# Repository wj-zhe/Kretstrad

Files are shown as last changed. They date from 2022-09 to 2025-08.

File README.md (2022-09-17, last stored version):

# Kretsträd - a Seeeduino Xiao BLE based 34 keys split keyboard running on ZMK firmware

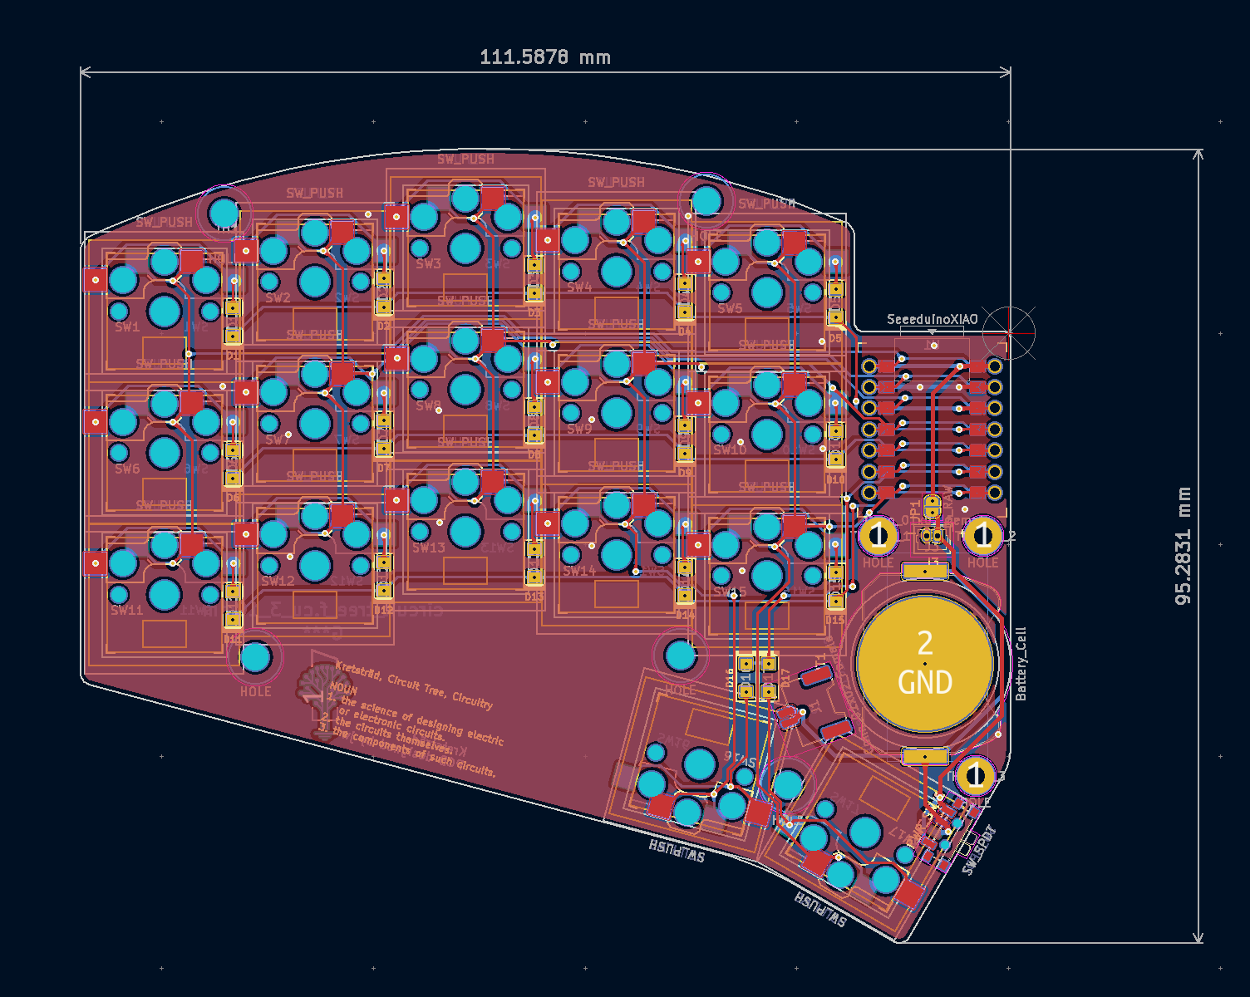
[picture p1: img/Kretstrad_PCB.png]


## Build instruction

This keyboard is able to accommodate two types of batteries. My own prototypes used two LIR2032
rechargeable cell batteries, simply because they seem to be more geeky to my eyes. In such case, all
you have to buy is No.1-10 on BOM list. However, the small 40 mAh capacity requires a charge every
5-7 days on master side and roughly 14 days on peripheral side.

So, if you prefer longivity and less frequent charge, use 501220 lithium ion battery pack rated at
100 mAh. In this case, you should buy everything on BOM except No.9-10. Also, remember to close JP1
jumper on the back side.

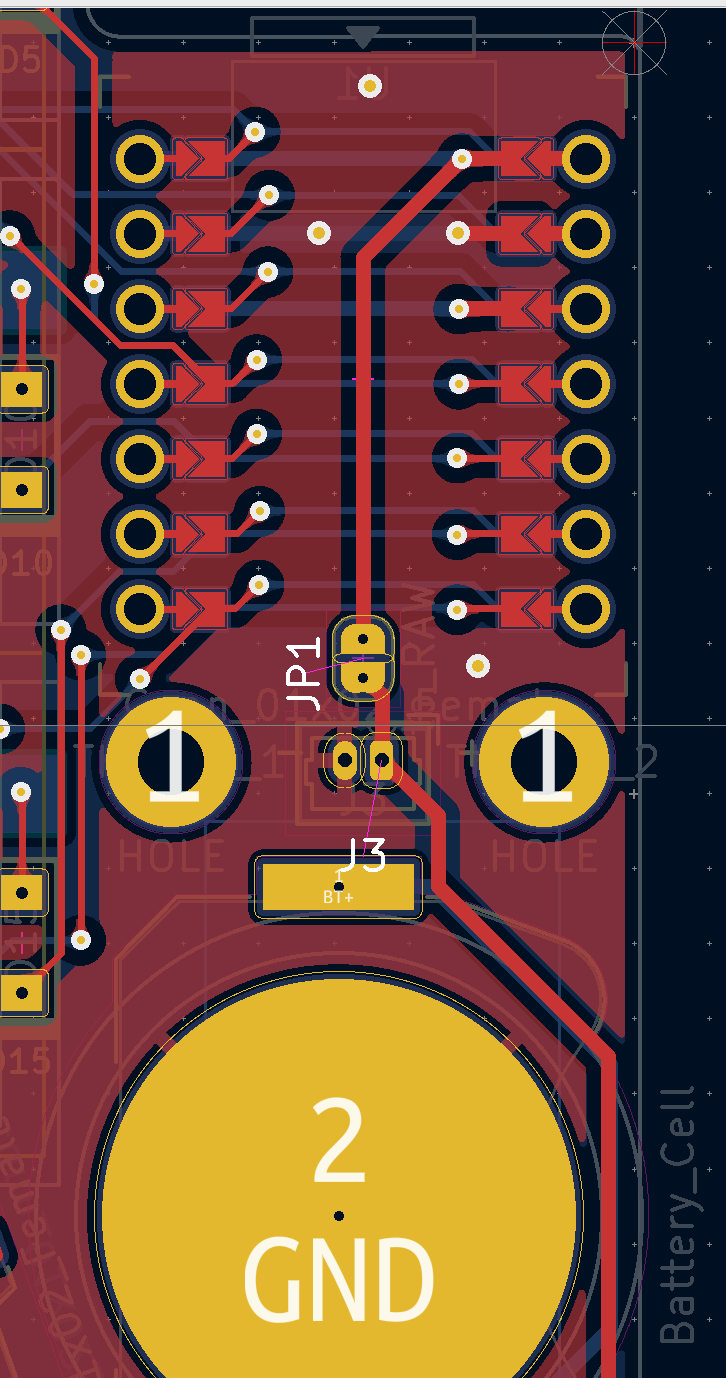
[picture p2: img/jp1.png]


Other than that, the build process is quite straight forward:
  - order PCB with readily printable [gerber files](/pcb/gerber). [KiCad files](/pcb) are also in
    place, incase you want to make change;
  - buy components depending on battery type;
  - solder everything into place
  - put in Kailh Choc V1 switches. Yes, this keyboard supports only V1 Choc as for now;
  - Done!

Files for acrylic stacked case are located in [/case](/case) directory. But only cell battery
version is provided. If you chose 501220 battery pack, please remember to make correspondent
modifications.

In case MCU/battery covers are needed, you can draw yourself based on case files and install them
with additional M2x9+3 brass insert spacers placed at TH_PCB_1 ~ TH_PCB_3.

## BOM

| No. | Designator | Package | Quantity |
| :--- | :--- | :--- | :--- |
| 1  | U1 | Seeeduino Xiao BLE (nRF52840) | 2 |
| 2  | D1 ~ D17 | Diode SOD123 THT 1N4148WS 1206 | 34 |
| 3  | SW1 ~ SW17 | Kailh CHOC switch socket PG1350 | 34 |
| 4  | TH1 ~ TH5 | Brass insert M2x5 | 10 |
| 5  | TH1 ~ TH5 | M2x3 flat head screws | 20 |
| 6  | TH_PCB_1 ~ TH_PCB_3 | Plated self-clinching standoff, M2x3 | 6 |
| 7  | TH_PCB_1 ~ TH_PCB_3 | M2x5 flat head screws | 6 |
| 8  | PWR_SW_1,PWR_SW_2 | PCM12SMTR | 2 |
| 9  | J3 | Molex_PicoBlade_53047-0210_1x02_P1.25mm_Vertical,1 | 2 |
| 10 | BT1,BT2 | Battery Holder BK-912 | 2 |
| 11 | J1,J2 | Molex_Panelmate_53780-0270_1x02-1MP_P1.25mm_Horizontal,2 | 2 |

## Firmware

https://github.com/wj-zhe/zmk-config/tree/master/config/boards/shields/kretstrad

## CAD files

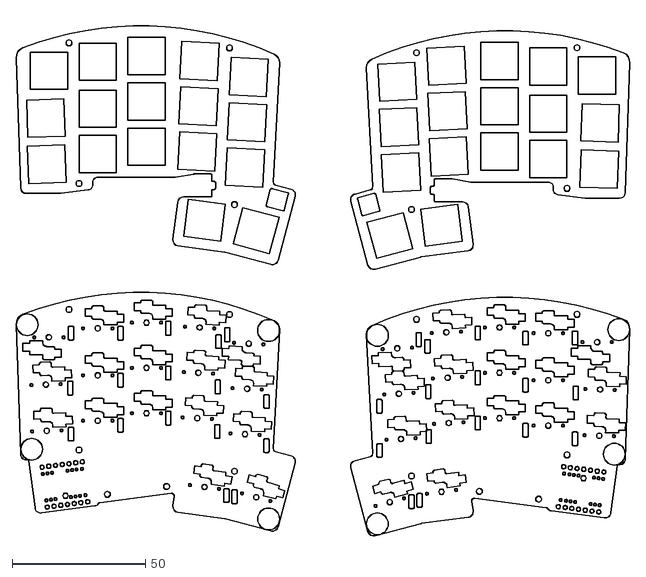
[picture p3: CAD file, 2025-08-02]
case/dxf/Kretsträd_v2-Edge_Cuts.dxf
230.3 x 195.2

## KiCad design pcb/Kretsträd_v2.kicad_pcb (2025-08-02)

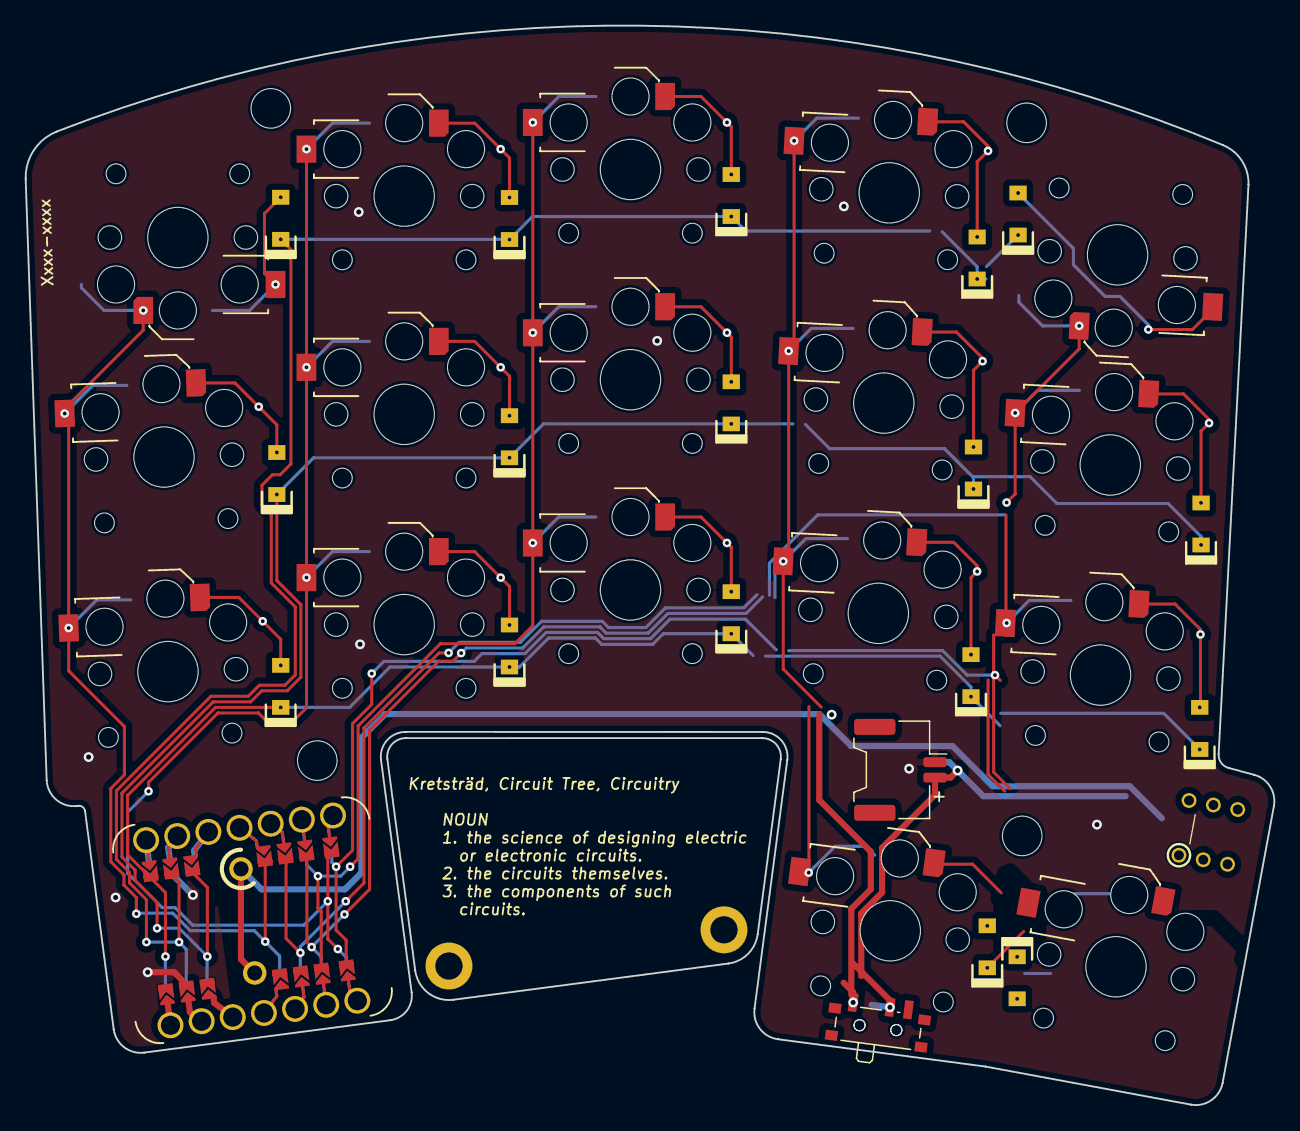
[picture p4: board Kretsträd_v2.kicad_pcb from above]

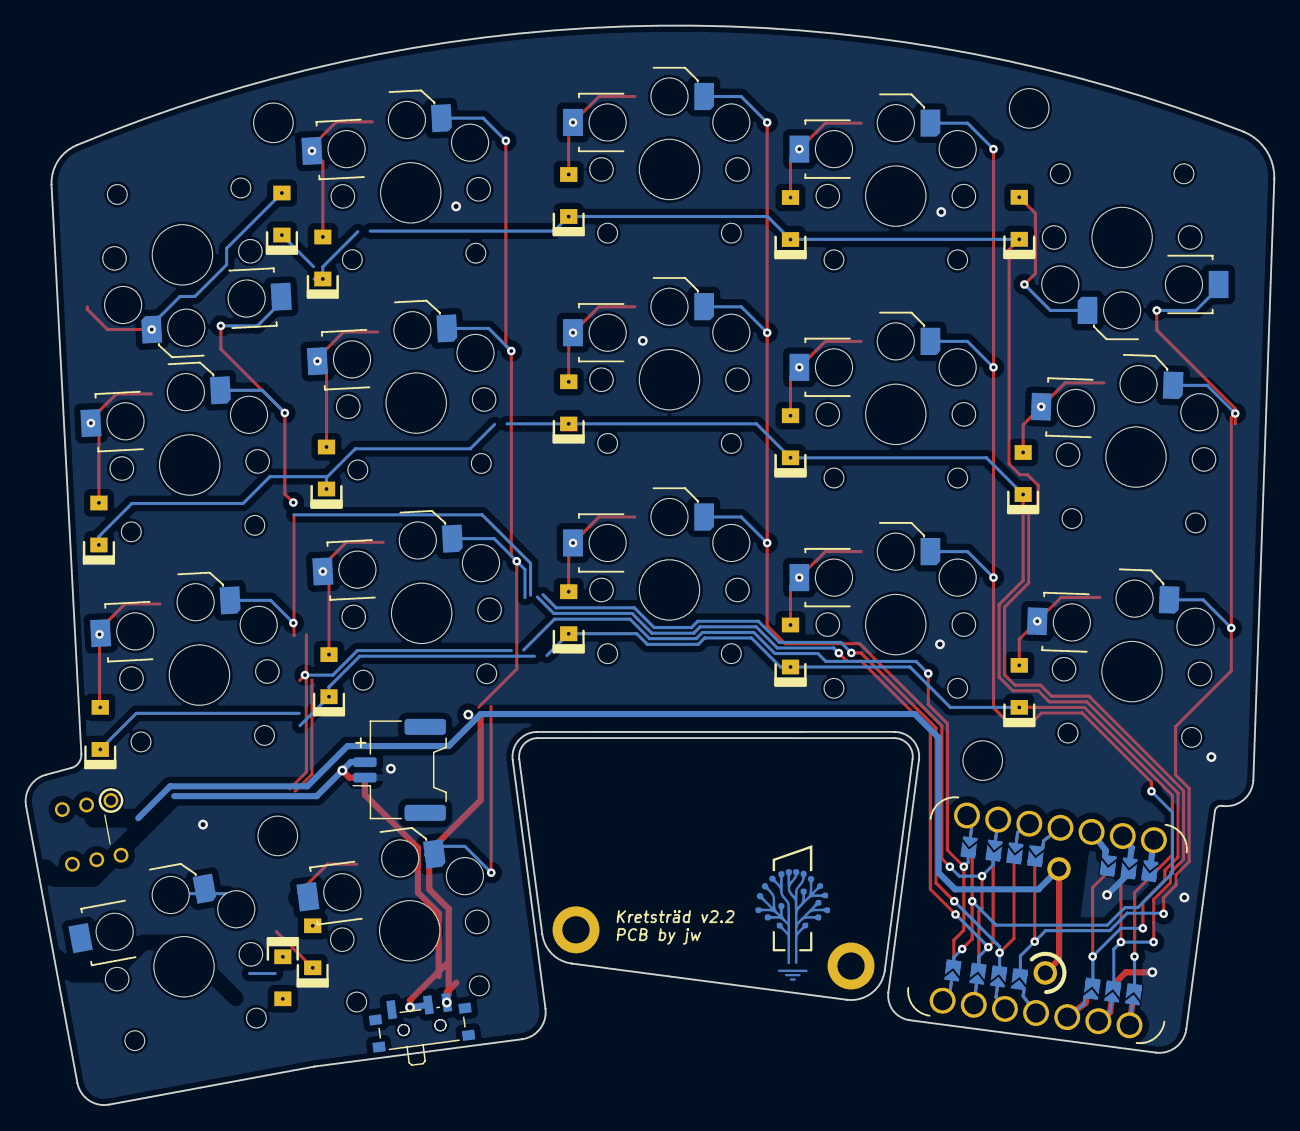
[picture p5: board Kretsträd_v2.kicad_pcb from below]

Board: 2 copper layers, 101.0 x 87.3 mm, 48 parts (2 on the bottom side), 29 nets.

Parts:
Batt_Hole_1, Batt_Hole_2: HOLE; MountingHole_2.2mm_M2_ISO14580_Pad
D1, D2, D3, D4, D5, D6, D7, D8, D9, D10, D11, D12, D13, D14, D15, D16, D17: D; Diode_SOD123_THT_v3
J1, J2: Conn_01x02_Female; Molex_Panelmate_53780-0270_1x02-1MP_P1.25mm_Horizontal
J3, J4: Conn_01x01_Socket; Pogopin_socket_1x01_1.20mm_vertical
PWR_SW_1, PWR_SW_2: SW_SPDT; SW_SPDT_PCM12
PWR_SW_3: SW_DPDT; Button_Switch_Push_Vertical_2P2T_Toggle_5.8x5.8
SW1: SW1; Kailh_Choc_PG1350_v1+2_Hotswap_reversible
SW2: SW2; Kailh_Choc_PG1350_v1+2_Hotswap_reversible
SW3: SW3; Kailh_Choc_PG1350_v1+2_Hotswap_reversible
SW4: SW4; Kailh_Choc_PG1350_v1+2_Hotswap_reversible
SW5: SW5; Kailh_Choc_PG1350_v1+2_Hotswap_reversible
SW6: SW6; Kailh_Choc_PG1350_v1+2_Hotswap_reversible
SW7: SW7; Kailh_Choc_PG1350_v1+2_Hotswap_reversible
SW8: SW8; Kailh_Choc_PG1350_v1+2_Hotswap_reversible
SW9: SW9; Kailh_Choc_PG1350_v1+2_Hotswap_reversible
SW10: SW10; Kailh_Choc_PG1350_v1+2_Hotswap_reversible
SW11: SW11; Kailh_Choc_PG1350_v1+2_Hotswap_reversible
SW12: SW12; Kailh_Choc_PG1350_v1+2_Hotswap_reversible
SW13: SW13; Kailh_Choc_PG1350_v1+2_Hotswap_reversible
SW14: SW14; Kailh_Choc_PG1350_v1+2_Hotswap_reversible
SW15: SW15; Kailh_Choc_PG1350_v1+2_Hotswap_reversible
SW16: SW16; Kailh_Choc_PG1350_v1+2_Hotswap_reversible
SW17: SW17; Kailh_Choc_PG1350_v1+2_Hotswap_reversible
TH1, TH2, TH3, TH4: HOLE; MountingHole_3.2mm_M3
U1: SeeeduinoXIAO_nRF52840; Xiao_nRF52840_THT_jumper_1.55mm_hole

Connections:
BAT: J3.1, J4.1, PWR_SW_1.1 (A), PWR_SW_2.3 (C), PWR_SW_3.2 (B), PWR_SW_3.5 (B)
BT+: J1.2, J2.2, PWR_SW_1.2 (B), PWR_SW_2.2 (B), PWR_SW_3.3 (C), PWR_SW_3.6 (C)
GND: J1.1, J2.1, U1.12 (GND)
unnamed: D1.2 (A), SW1.1
unnamed: D2.2 (A), SW2.2
unnamed: D3.2 (A), SW3.2
unnamed: D4.2 (A), SW4.2
unnamed: D5.2 (A), SW5.1
unnamed: D6.2 (A), SW6.2
unnamed: D7.2 (A), SW7.2
unnamed: D8.2 (A), SW8.2
unnamed: D9.2 (A), SW9.2
unnamed: D10.2 (A), SW10.2
unnamed: D11.2 (A), SW11.2
unnamed: D12.2 (A), SW12.2
unnamed: D13.2 (A), SW13.2
unnamed: D14.2 (A), SW14.2
unnamed: D15.2 (A), SW15.2
unnamed: D16.2 (A), SW16.2
unnamed: D17.2 (A), SW17.2
col0: SW1.2, SW6.1, SW11.1, U1.3 (P0.29/A3_D3)
col1: SW2.1, SW7.1, SW12.1, U1.6 (P1.11/A6_D6/TX)
col2: SW3.1, SW8.1, SW13.1, U1.8 (P1.13/A8_D8/SCK)
col3: SW4.1, SW9.1, SW14.1, SW16.1, U1.5 (P0.05/A5_D5/SCL)
col4: SW5.2, SW10.1, SW15.1, SW17.1, U1.4 (P0.04/A4_D4/SDA)
row0: D1.1 (K), D2.1 (K), D3.1 (K), D4.1 (K), D5.1 (K), U1.1 (P0.03/A1_D1)
row1: D6.1 (K), D7.1 (K), D8.1 (K), D9.1 (K), D10.1 (K), U1.2 (P0.28/A2_D2)
row2: D11.1 (K), D12.1 (K), D13.1 (K), D14.1 (K), D15.1 (K), U1.0 (P0.02/A0_D0)
row3: D16.1 (K), D17.1 (K), U1.7 (P1.12/A7_D7/RX)

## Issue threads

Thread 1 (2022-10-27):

Question about the design

cirias, 2022-10-27:
Hello,
I can only find the PCB file for the left half. I think it can be flipped to be the right half. But I'm confused about the circuits connecting the control board. It looks like all the pads in the same row are shorted. My guess is one have to manually cut the traces, and the way you cut them decide which half it will be. Am I correct about this? Is this common for split keyboard design? And how can this pass the Kicad rules checker without causing any violation?

Sorry about throwing so many questions to you. I'm trying to design my own keyboard and I saw yours. It inspires me so much! If you ever get a chance to take a look, it will mean a lot to me!

cirias, 2022-10-27:
I just figured. The pad is actually a two pads connector after zoom in... No question now. But still want to appreciate you for the amazing project!

wj-zhe, 2022-10-27:
Glad you figured it out. Feel free to contact me on any issue.

Closed 2022-10-27.

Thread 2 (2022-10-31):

What is the purpose of JP1?

cirias, 2022-10-31:
After solder JP1, BAT+ connects to RAW, which is 5V from the USB. Wouldn't that damage the battery?

The doc mentioned it should only be soldered when using a external lipo battery, like 501220. But how would the battery connect the board? The doc also said J3 is not needed. So I guess the battery will be going to either directly to the board or through J1/J2. But in either case, I still don't see a reason to solder JP1.

Could you point out what I'm missing? Thank you in advance!

wj-zhe, 2022-10-31:
Basically:
- If you're using lipo battery, like 501220, buy a connector, solder it to J1, and connect JP1
- If you're using cell battery, buy BK-912 battery holder, buy Molex_PicoBlade_53047-0210_1x02_P1.25mm_Vertical and solder it to J3

Maybe I should re-rewrite the manual in the future.

cirias, 2022-11-01:
Thanks for the info! But I'm still confused.
1. When using lipo battery, are you saying the battery gives power through RAW? But isn't RAW 5 volt when USB is connected? So one have to remove the battery when connecting USB?
2. When using cell battery, why even need Molex_PicoBlade_53047-0210_1x02_P1.25mm_Vertical? Doesn't BK-912 already connect the battery to J1?

wj-zhe, 2022-11-01:
Connect lipo battery via RAW is recommendation from Seeeduino, but I personally haven't tried it out and hence cannot give you a precise answer.

J1 (and J2) on opposite site is for lipo type batt. It's BT+ is connected with battery holder which then connects to J3 but with a switch between them.

You can open up schematic to have a better understanding.

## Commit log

2022-06-24 Traces completely re-routed.
    [Kretsträd.kicad_pcb, Kretsträd.kicad_sch]
2022-06-24 Minor change in front silkscreen text.
    [Kretsträd.kicad_pcb]
2022-06-25 Tones of changes.
    [Kretsträd.kicad_pcb, Kretsträd.kicad_sch]
2022-07-04 Moved position of CR2032 battery holder, some mounting holes.
    [Kretsträd.kicad_pcb]
2022-07-07 1. Corrected all vias' size. 2. Minor change to circuit tree logo and text. 3. Other changes for aesthetics reasons.
    [Kretsträd.kicad_pcb, Kretsträd.kicad_sch]
2022-07-07 Included gerber files.
    [Kretsträd-B_Cu.gbr, Kretsträd-B_Mask.gbr, Kretsträd-B_Silkscreen.gbr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]
2022-07-07 1. Modified LIR2032 battery holder footprint. 2. Changed Molex 1.25 battery female connector location. 3. Minor changes.
    [Kretsträd-B_Cu.gbr, Kretsträd-B_Mask.gbr, Kretsträd-B_Silkscreen.gbr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]
2022-07-08 1. Updated switch footprint to increase solder pad size. 2. Squeezed MCU LIR2032 battery holder power switch section. 3. Re-routed a lot. 4. Reduced curvature on edge under thumb keys. 5. Removed pow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
    [Kretsträd-B_Cu.gbl, Kretsträd-B_Cu.gbr, Kretsträd-B_Mask.gbs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]
2022-07-10 Minor changes here and there.
    [Kretsträd-B_Cu.gbl, Kretsträd-B_Mask.gbs, Kretsträd-B_Silkscreen.gbo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]
2022-07-13 1. Moved down col0 and col1 (out-most columns). 2. Rerouted alot to avoid 'dead zones'. 3. Added tear drops for the same reason. 4. Minor change to edge shape. 5. Other minor changes.
    [Kretsträd-B_Cu.gbl, Kretsträd-B_Mask.gbs, Kretsträd-B_Silkscreen.gbo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]
2022-07-14 No comment.
    [Kretsträd-B_Cu.gbl, Kretsträd-B_Mask.gbs, Kretsträd-B_Silkscreen.gbo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]
2022-07-14 Forgot to add tear-drops in previous commit.
    [Kretsträd-B_Cu.gbl, Kretsträd-B_Mask.gbs, Kretsträd-B_Silkscreen.gbo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]
2022-07-19 First PCB production.
    [Kretsträd-B_Cu.gbl, Kretsträd-B_Mask.gbs, Kretsträd-B_Silkscreen.gbo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]
2022-09-17 First public version.
    [Kretsträd-B_Cu.gbl, Kretsträd-B_Mask.gbs, Kretsträd-B_Silkscreen.gbo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]
2024-02-12 Re-oganized last version into rev1 directory.
    [Kretsträd-B_Cu.gbl, Kretsträd-B_Mask.gbs, Kretsträd-B_Silkscreen.gbo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]
2024-02-12 Deleted old files.
    [Kretsträd-B_Cu.gbl, Kretsträd-B_Mask.gbs, Kretsträd-B_Silkscreen.gbo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]
2024-02-12 Added rev2
    [Kretsträd_v2-B_Cu.gbl, Kretsträd_v2-B_Mask.gbs, Kretsträd_v2-B_Silkscreen.gbo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]
2024-04-05 Rev2 completely redesigned
    [Kretsträd_v2-B_Cu.gbl, Kretsträd_v2-B_Mask.gbs, Kretsträd_v2-B_Silkscreen.gbo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]
2024-07-14 Created Kailh PG1316 based Kretsträd. 3D print case not designed.
    [Kretsträd_v2_PG1316-B_Cu.gbl, Kretsträd_v2_PG1316-B_Mask.gbs, Kretsträd_v2_PG1316-B_Silkscreen.gbo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]
2024-07-14 Created separated directory for choc version Kretsträd
    [Kretsträd_v2-B_Cu.gbl, Kretsträd_v2-B_Mask.gbs, Kretsträd_v2-B_Silkscreen.gbo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]
2025-01-02 v2.1: pre-production iteration
    [Kretsträd_v2-B_Cu.gbl, Kretsträd_v2-B_Mask.gbs, Kretsträd_v2-B_Silkscreen.gbo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]
2025-01-03 v2: pre-production: added supplementary power switches; tweaks here and there
    [Kretsträd_v2-B_Cu.gbl, Kretsträd_v2-B_Mask.gbs, Kretsträd_v2-B_Silkscreen.gbo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]
2025-01-08 v2.1: first production
    [Kretsträd_v2-B_Cu.gbl, Kretsträd_v2-B_Mask.gbs, Kretsträd_v2-B_Silkscreen.gbo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]
2025-05-30 v2: Modified v2 pcb, built stack-style case
    [Kretsträd_v2 copy.kicad_pcb, Kretsträd_v2-Edge_Cuts.dxf, Kretsträd_v2-prototyping.dxf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]
2025-08-02 Reorganized directory, leaving v2.2 and making changes for v2.3
    [Kretsträd_v2-Edge_Cuts.dxf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]
